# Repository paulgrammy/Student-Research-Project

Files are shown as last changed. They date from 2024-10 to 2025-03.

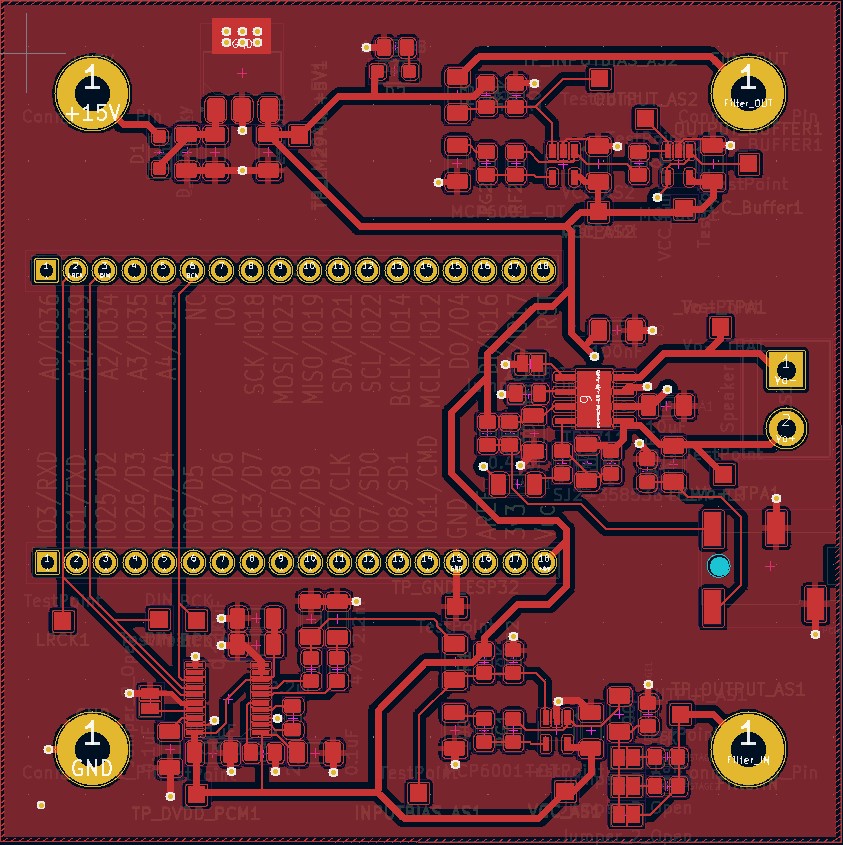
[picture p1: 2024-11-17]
doc/PCB Schematicc.jpg

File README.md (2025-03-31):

# Student-Research-Project-
Bluetooth signal receiver with filter stage and AUX/Speaker output.

UseCase description: 

This project seeks to help students more easily understand the effects of filters on electric signals by using sound. Since Music and/or audio is composed of frequencies across a spectrum (20Hz to 20kHz), one can hear what an Low/High Pass filter would do when fed audio signals. In my Student-Research project work, I try to design a PCB that shall overline this use case.

The PCB shall process analog converted audio signal coming from a Bluetooth-capable ESP32 board. The user shall connect the board at the input and output of any given filter and shall have the option to hear the filtered and unfiltered audio signals coming out with minimal noise and distortion.

Used platforms and ICs:

- ESP32 FireBeetle board:
    https://wiki.dfrobot.com/FireBeetle_Board_ESP32_E_SKU_DFR0654
- PCM5102 DAC:
    https://www.ti.com/product/PCM5102
- MCP6001 OPAMPS:
    https://ww1.microchip.com/downloads/en/DeviceDoc/MCP6001-1R-1U-2-4-1-MHz-Low-Power-Op-Amp-DS20001733L.pdf
- TPA711 Power AMP:
    https://www.ti.com/product/TPA711

Potential software solutions for the BluetoothRx interface:

https://github.com/pschatzmann/ESP32-A2DP

https://github.com/YetAnotherElectronicsChannel/ESP32_Bluetooth_Audio_Receiver

Books and Papers:

https://web.mit.edu/6.101/www/reference/op_amps_everyone.pdf

End result:
PCB 3D View

Conclusions: 
The board works with minimal distortion up to the OpAmps single supply limits, offering almost no phase lag.
Some layout optimizations can be carried out to lower the noise floor and make implementation in the labs easier.

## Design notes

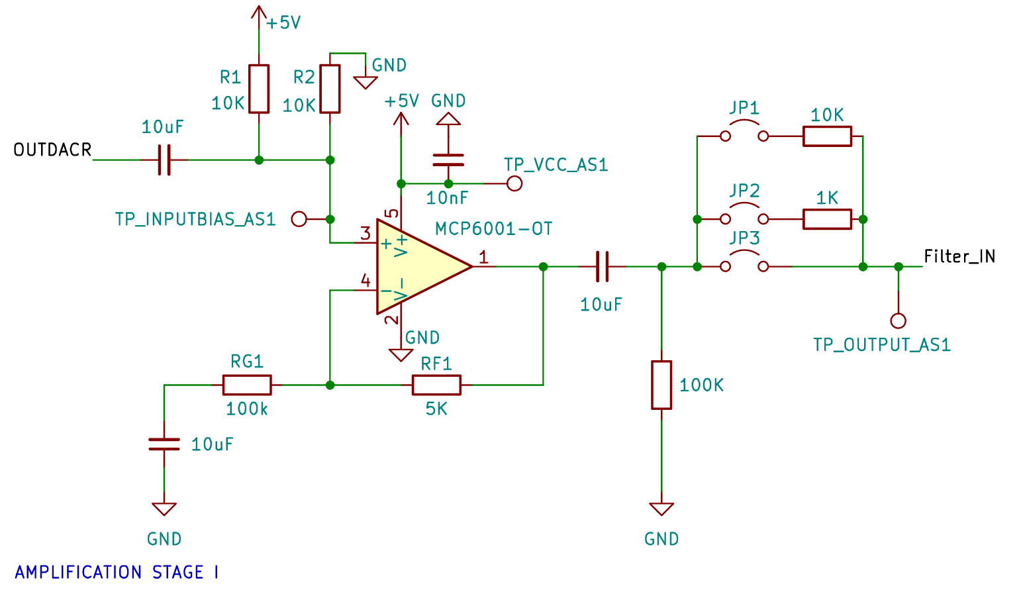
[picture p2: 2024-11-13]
doc/Schematic_OPAMP1.png

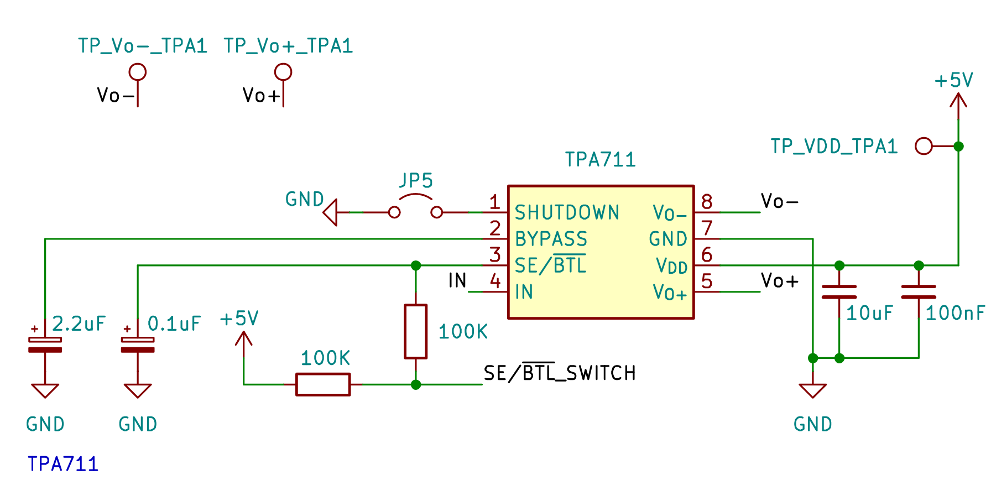
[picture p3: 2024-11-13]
doc/Schematic_POWERAMP.png

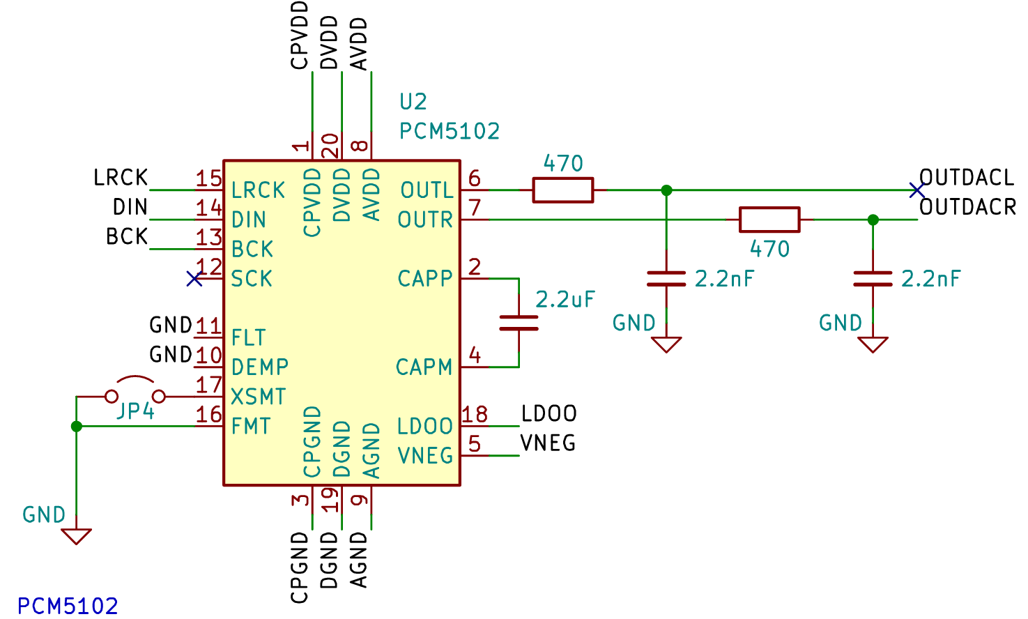
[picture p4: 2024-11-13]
doc/Schematic_DAC.png

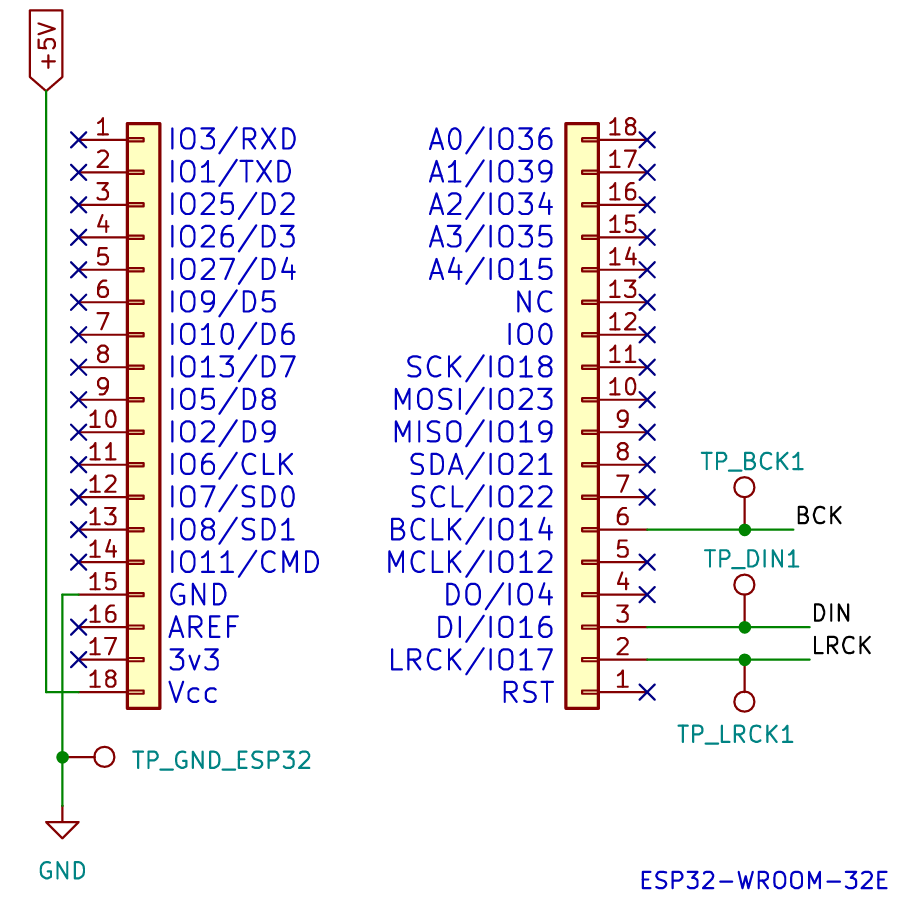
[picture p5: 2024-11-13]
doc/Schematic_ESP.png

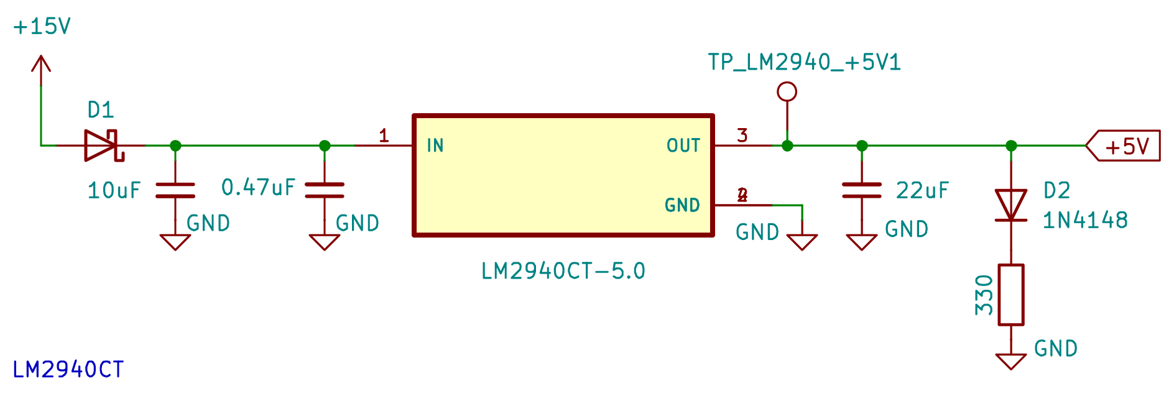
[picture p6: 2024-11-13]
doc/Schematic_LDO.png

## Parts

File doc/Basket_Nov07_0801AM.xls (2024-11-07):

SHOPPING BASKET
This is not an invoice
07-Nov-24 08:01:21
 | Mouser No | Mfr. No | Manufacturer | Customer No | Description | RoHS | Lifecycle | Order Qty. | Price (EUR) | Ext.: (EUR) | Comment
1 | 595-TPA711DR | TPA711DR | Texas Instruments |  | Audio Amplifiers 700mW Lw V Audio | RoHS Compliant |  | 3 | 1,09 € | 3,27 €
2 | 651-1729128 | 1729128 | Phoenix Contact |  | Fixed Terminal Blocks 2P 5.08mm 90DEG | RoHS Compliant By Exemption |  | 3 | 0,967 € | 2,90 €
3 | 595-PCM5102AQPWRQ1 | PCM5102AQPWRQ1 | Texas Instruments |  | Audio D/A Converter ICs 2VRMS DirectPath Audio Stereo DAC | RoHS Compliant |  | 3 | 5,04 € | 15,12 €
4 | 579-MCP6001UT-I/OT | MCP6001UT-I/OT | Microchip |  | Operational Amplifiers - Op Amps Single 1.8V 1MHz | RoHS Compliant |  | 6 | 0,279 € | 1,67 €
5 | 926-LM2940CT50LF01 | LM2940CT-5.0/LF01 | Texas Instruments |  | LDO Voltage Regulators 1-A, 26-V, high-PSRR, low-dropout voltage regulator 3-TO-220 | RoHS Compliant By Exemption |  | 3 | 1,74 € | 5,22 €
6 | 621-1N5819HW-F | 1N5819HW-7-F | Diodes Incorporated |  | Schottky Diodes & Rectifiers Vr/40V Io/1A T/R | RoHS Compliant |  | 3 | 0,233 € | 0,70 €
7 | 179-SJ3-35083A-TR | SJ3-35083A-TR | Same Sky |  | Phone Connectors Audio Jack, 3.5mm, Through Hole, 3 Conductors, 0 Switches | RoHS Compliant | New Product | 3 | 1,14 € | 3,42 €
8 | 78-1N4148W-HG3_A-08 | 1N4148W-HG3_A-08 | Vishay |  | Small Signal Switching Diodes |  | New Product | 3 | 0,307 € | 0,92 €
By submitting your order you agree to these terms and conditions. (https://www.mouser.de/saleterms) |  |  |  |  |  |  |  |  | Merchandise: | 33,22 €
Prices are reflected at the date and time shown. |  |  |  |  |  |  |  |  | Delivery Charge: | 20,00 €

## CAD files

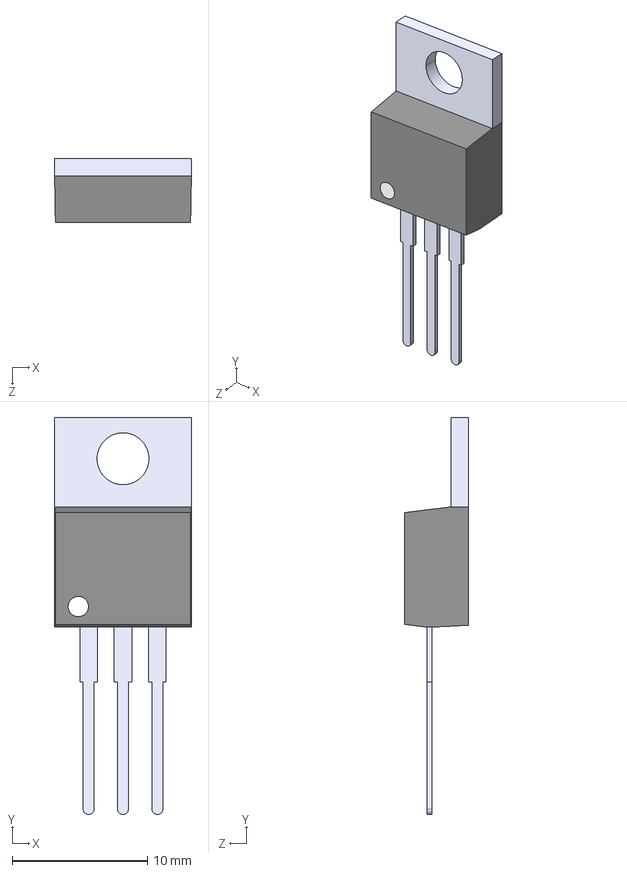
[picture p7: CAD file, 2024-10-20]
footprints/LM2940-5.0/LM2940CT-5.0.step
10.2 x 29.3 x 4.70 mm

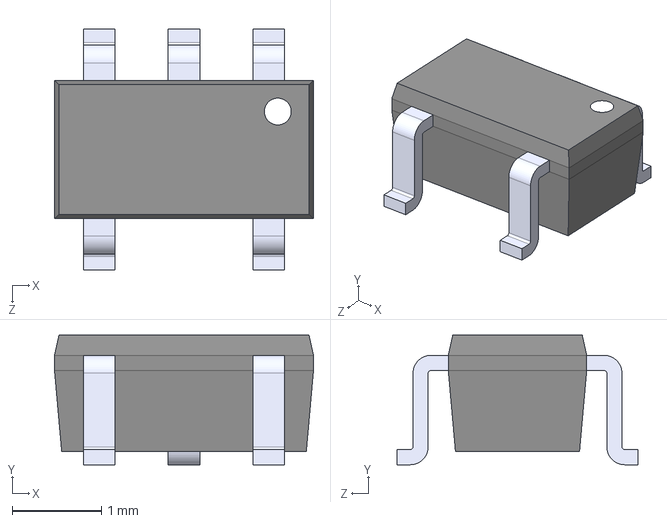
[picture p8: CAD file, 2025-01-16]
footprints/MCP6001UT-1_OT/MCP6001UT-I_OT.step
2.90 x 1.45 x 2.70 mm

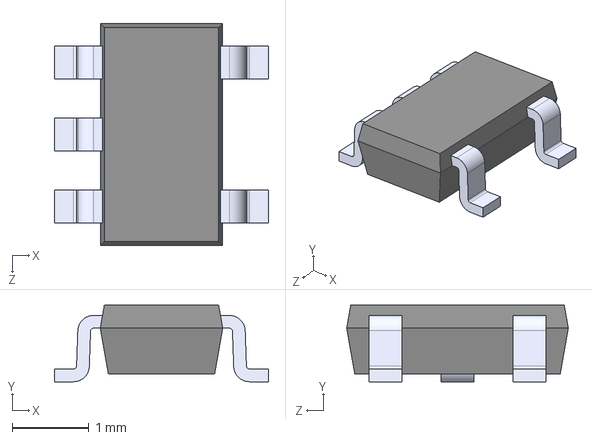
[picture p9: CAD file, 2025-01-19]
footprints/RT9080-33GJ5/RT9080-33GJ5.step
2.80 x 1.00 x 2.90 mm

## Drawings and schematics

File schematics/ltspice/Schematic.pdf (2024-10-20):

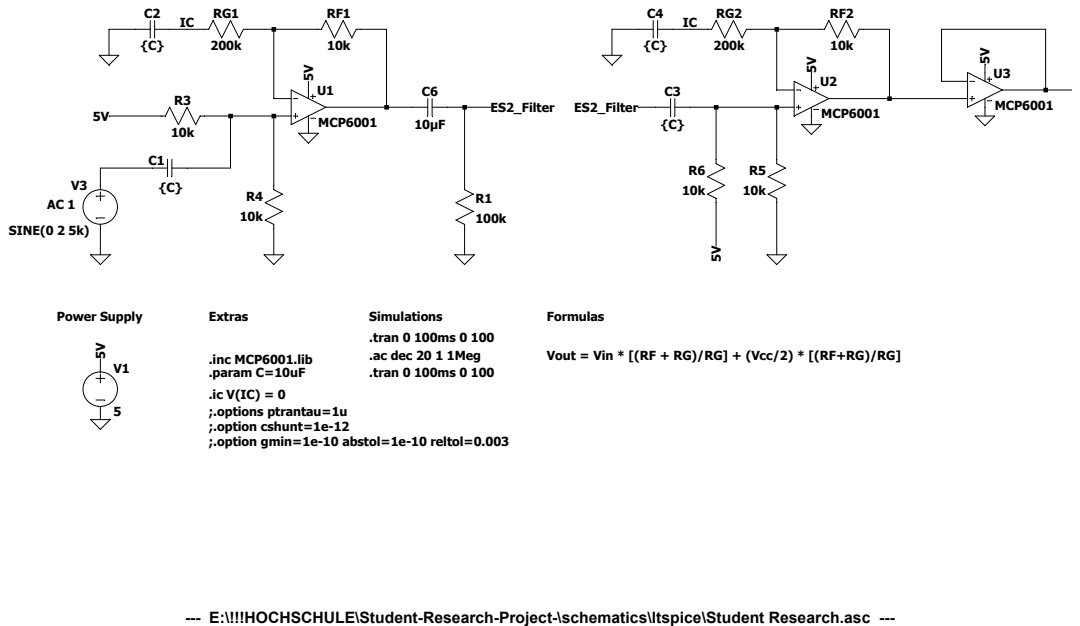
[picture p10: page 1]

.inc MCP6001.lib
.param C=10uF
;.options ptrantau=1u
;.option cshunt=1e-12
;.option gmin=1e-10 abstol=1e-10 reltol=0.003

Vout = Vin * [(RF + RG)/RG] + (Vcc/2) * [(RF+RG)/RG]

--- E:\!!!HOCHSCHULE\Student-Research-Project-\schematics\ltspice\Student Research.asc ---

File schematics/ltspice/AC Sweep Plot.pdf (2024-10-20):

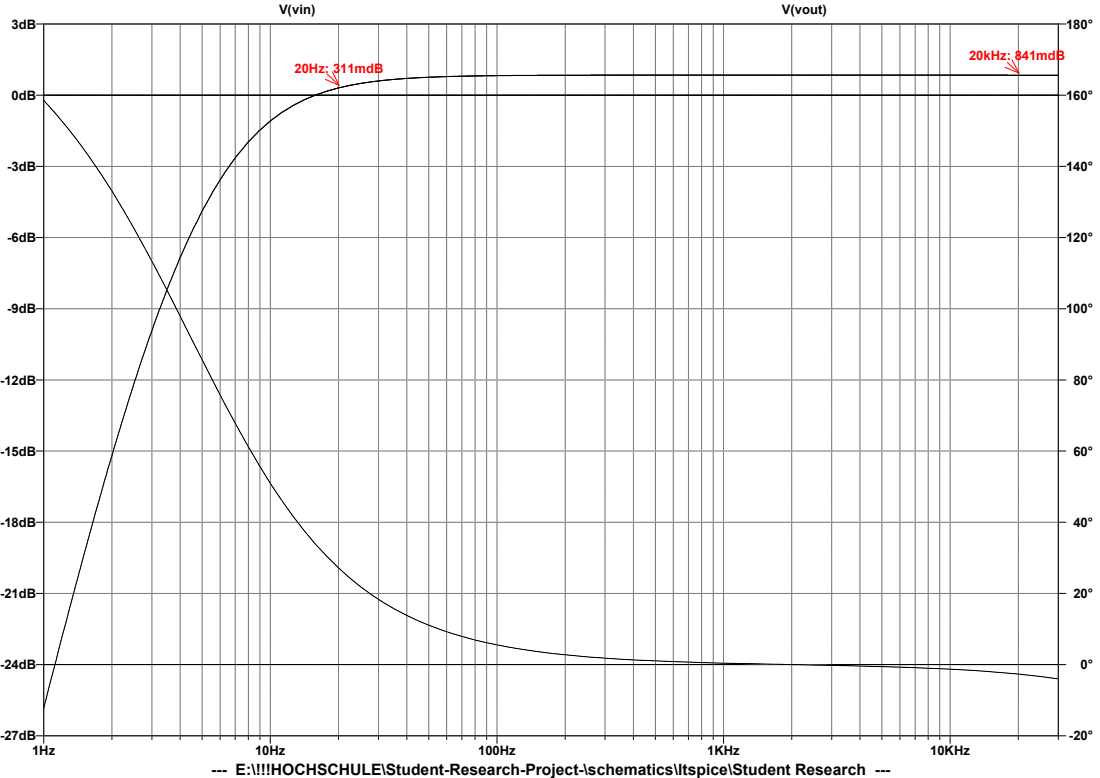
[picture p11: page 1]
1KHz; 10KHz; V(vin); V(vout); 20Hz: 311mdB; 20kHz: 841mdB

--- E:\!!!HOCHSCHULE\Student-Research-Project-\schematics\ltspice\Student Research ---

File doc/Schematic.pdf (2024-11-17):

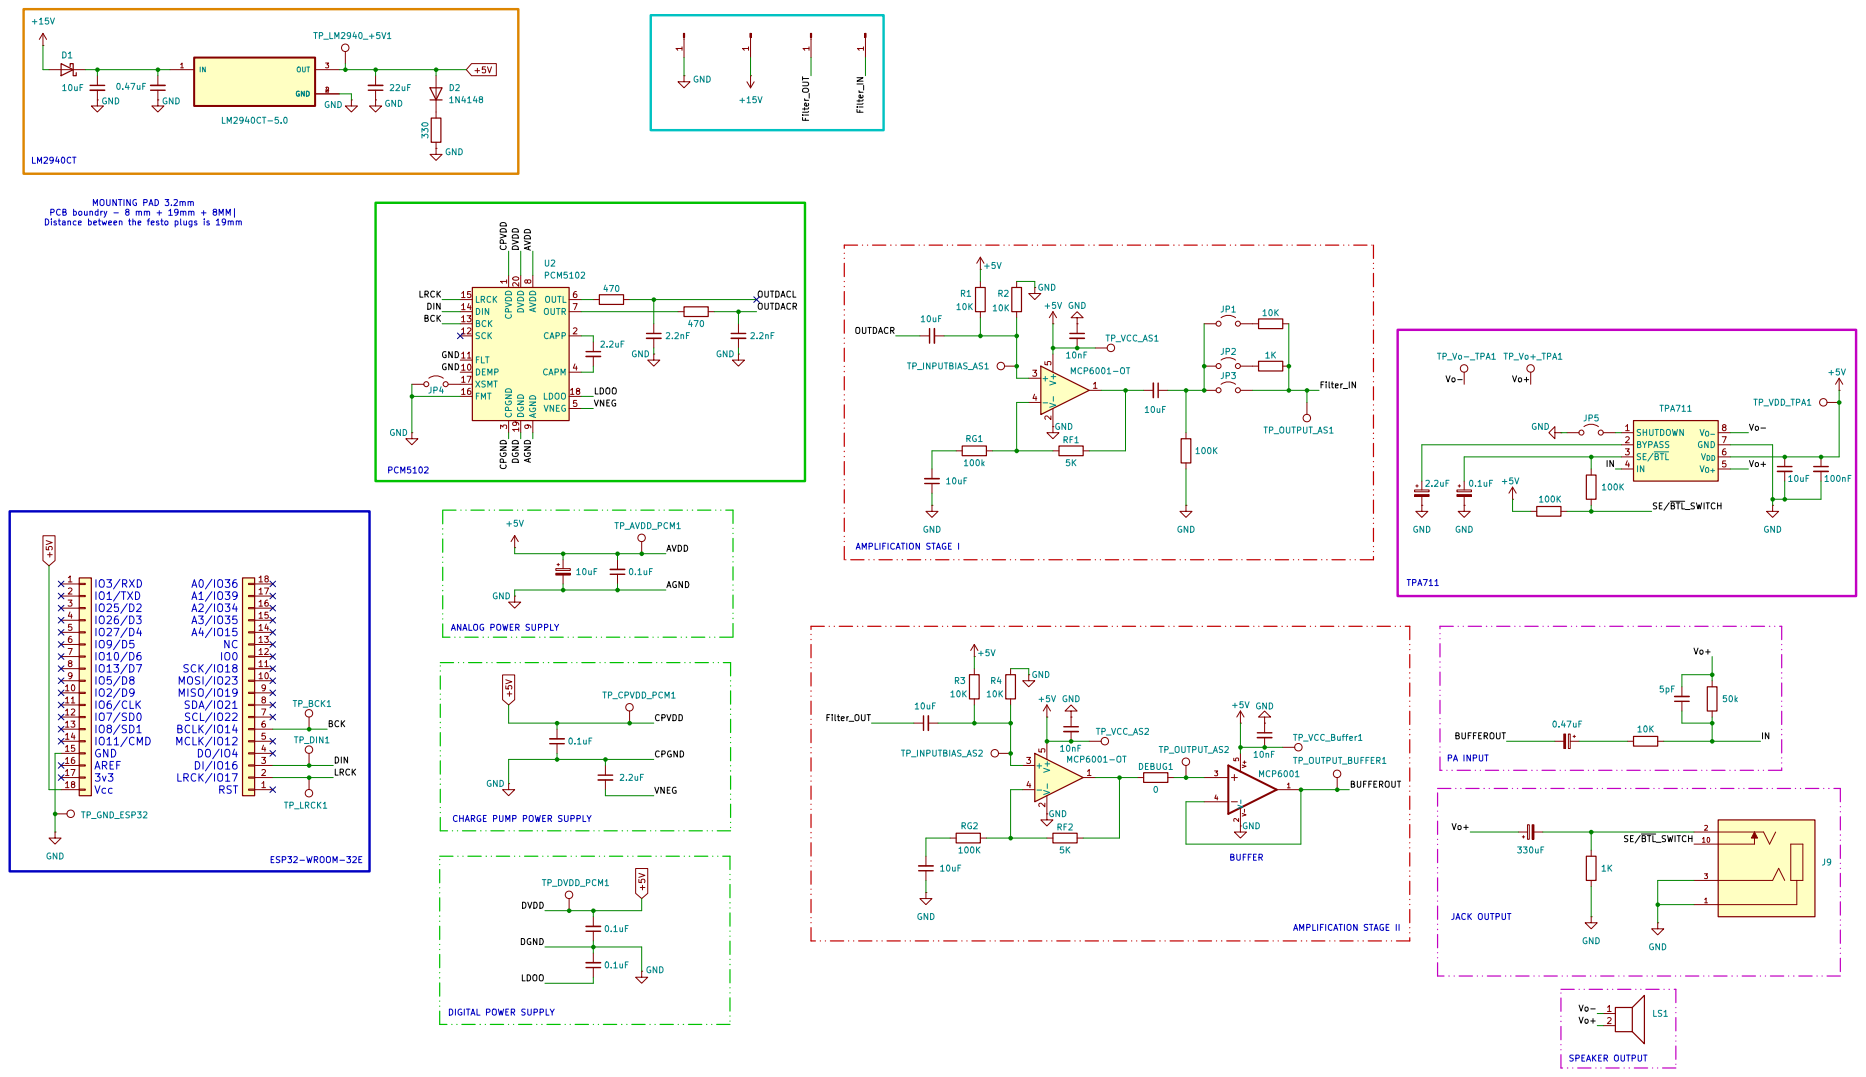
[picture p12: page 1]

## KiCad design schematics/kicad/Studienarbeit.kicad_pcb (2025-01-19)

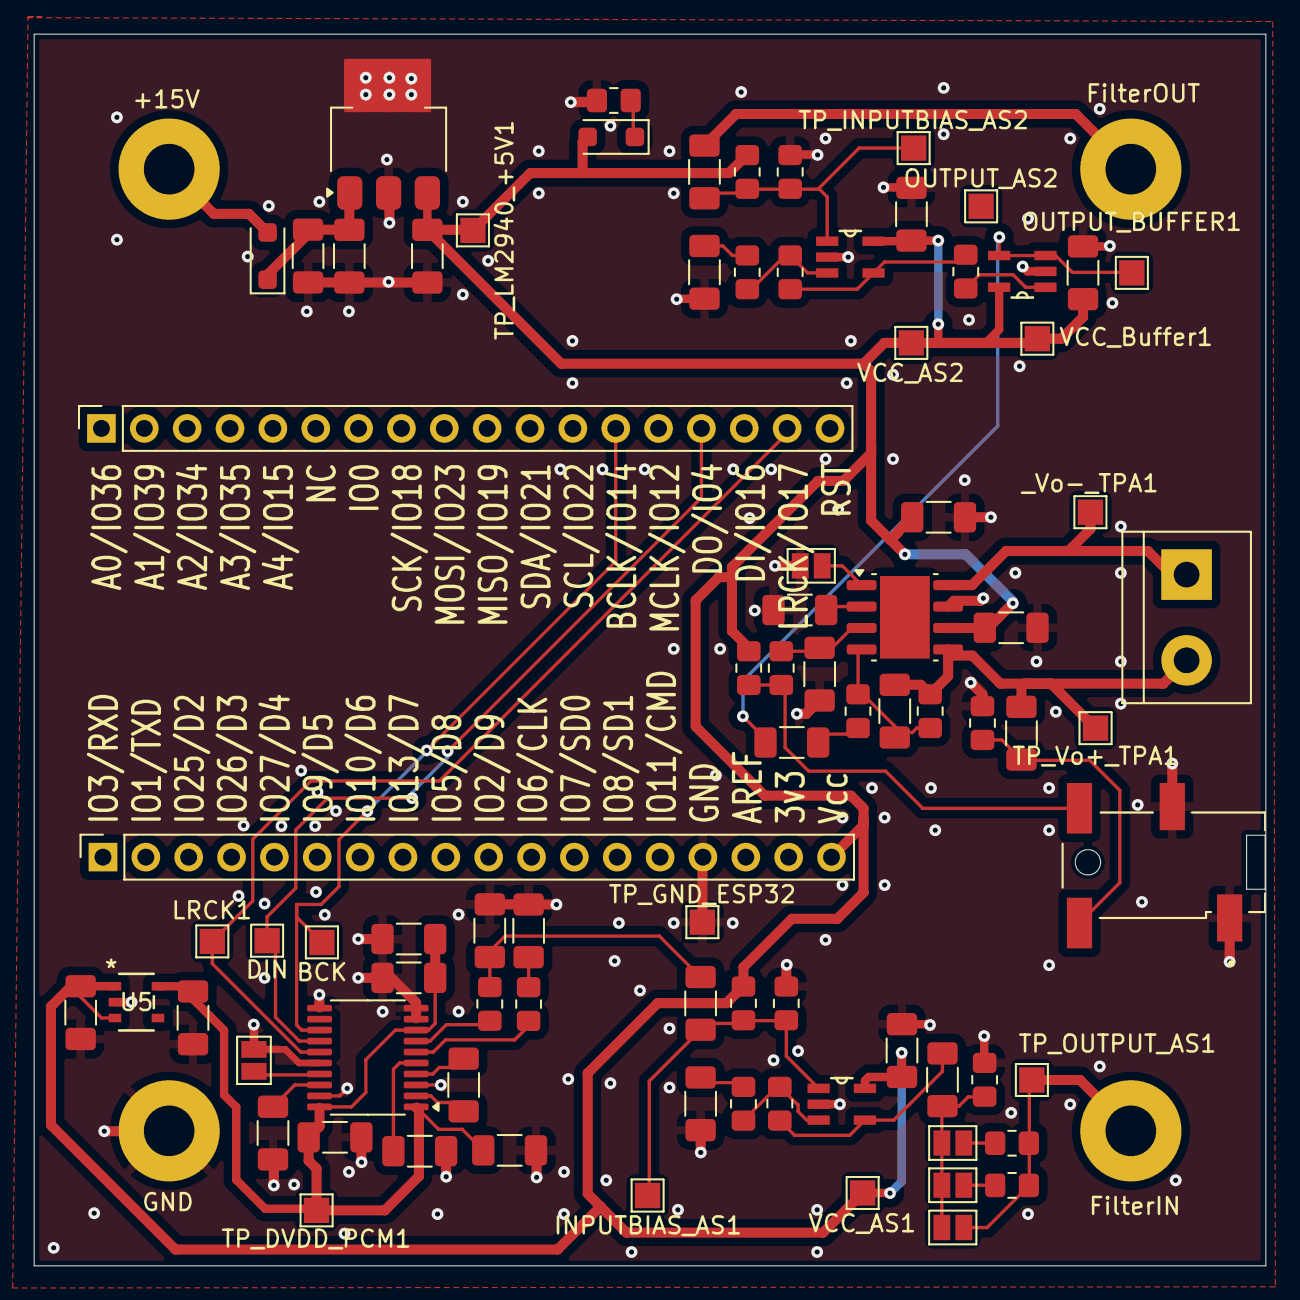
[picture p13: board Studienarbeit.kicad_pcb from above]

Board: 2 copper layers, 73.0 x 73.0 mm, 87 parts (0 on the bottom side), 42 nets.

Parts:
BCK: TestPoint; TestPoint_Pad_1.5x1.5mm
C1_APS_PCM5102: 10uF; C_1206_3216Metric_Pad1.33x1.80mm_HandSolder
C1_CPPS_PCM1, C1_DPS_PCM1, C2_APS_PCM5102, C2_DPS_PCM1: 0.1uF; C_1206_3216Metric_Pad1.33x1.80mm_HandSolder
C2_CPPS_PCM1: 2.2uF; C_1206_3216Metric_Pad1.33x1.80mm_HandSolder
CA_PCM5102: 2.2uF; C_1206_3216Metric_Pad1.33x1.80mm_HandSolder
CB_TPA1: 2.2uF; C_1206_3216Metric_Pad1.33x1.80mm_HandSolder
CF_TPA711: 5pF; C_1206_3216Metric_Pad1.33x1.80mm_HandSolder
CG1_PCM5102, CG2_PCM5102: 2.2nF; C_1206_3216Metric_Pad1.33x1.80mm_HandSolder
CI_TPA711: 0.47uF; C_1206_3216Metric_Pad1.33x1.80mm_HandSolder
C_COUPLING_AMPSTAGE1: 10uF; C_1206_3216Metric_Pad1.33x1.80mm_HandSolder
C_COUPLING_AMPSTAGE2, C_COUPLING_AMPSTAGE3, C_COUPLING_AMPSTAGE4: 10nF; C_1206_3216Metric_Pad1.33x1.80mm_HandSolder
C_GND_AMPSTAGE1, C_GND_AMPSTAGE2, C_GND_AMPSTAGE3: 10uF; C_1206_3216Metric_Pad1.33x1.80mm_HandSolder
C_INPUT_LDO1: 0.47uF; C_1206_3216Metric_Pad1.33x1.80mm_HandSolder
C_INPUT_RT1: 22uF; C_1206_3216Metric_Pad1.33x1.80mm_HandSolder
C_INPUT_RT9080: 1uF; C_1206_3216Metric_Pad1.33x1.80mm_HandSolder
C_INPUT_TPA1, C_INPUT_TPA3: 10uF; C_1206_3216Metric_Pad1.33x1.80mm_HandSolder
C_INPUT_TPA2: 100nF; C_1206_3216Metric_Pad1.33x1.80mm_HandSolder
C_IN_+15V_1: 10uF; C_1206_3216Metric_Pad1.33x1.80mm_HandSolder
C_IN_AMPSTAGE1: 10uF; C_1206_3216Metric_Pad1.33x1.80mm_HandSolder
C_OUTPUT_LDO1: 22uF; C_1206_3216Metric_Pad1.33x1.80mm_HandSolder
C_SE/BTL_TPA1: 0.1uF; C_1206_3216Metric_Pad1.33x1.80mm_HandSolder
D1: D_Schottky; D_SOD-123F
D2: 1N4148; D_SOD-123F
DEBUG1: 0; R_0805_2012Metric_Pad1.20x1.40mm_HandSolder
DIN: TestPoint; TestPoint_Pad_1.5x1.5mm
INPUTBIAS_AS1: TestPoint; TestPoint_Pad_1.5x1.5mm
J2, J3: Conn_01x18; PinSocket_1x18_P2.54mm_Vertical
J4, J5, J6, J7: Conn_01x01_Pin; FestoBoard_Drill_Hole
J9: SJ2-35853B-SMT-TR; CUI_SJ2-35853B-SMT-TR
JP1, JP2, JP3, JP4, JP5: Jumper_2_Open; SolderJumper-2_P1.3mm_Open_Pad1.0x1.5mm
LRCK1: TestPoint; TestPoint_Pad_1.5x1.5mm
LS1: Speaker; TerminalBlock_bornier-2_P5.08mm
OUTPUT_AS2: TestPoint; TestPoint_Pad_1.5x1.5mm
OUTPUT_BUFFER1: TestPoint; TestPoint_Pad_1.5x1.5mm
R1, R2, R3, R4: 10K; R_0805_2012Metric_Pad1.20x1.40mm_HandSolder
R11: 1K; R_0805_2012Metric_Pad1.20x1.40mm_HandSolder
R12, R13: 100K; R_0805_2012Metric_Pad1.20x1.40mm_HandSolder
RF1, RF2: 5K; R_0805_2012Metric_Pad1.20x1.40mm_HandSolder
RF_TPA711: 50k; R_0805_2012Metric_Pad1.20x1.40mm_HandSolder
RG1: 100k; R_0805_2012Metric_Pad1.20x1.40mm_HandSolder
RG2: 100K; R_0805_2012Metric_Pad1.20x1.40mm_HandSolder
RI_TPA711: 10K; R_0805_2012Metric_Pad1.20x1.40mm_HandSolder
ROUTDACL1: 470; R_0805_2012Metric_Pad1.20x1.40mm_HandSolder
ROUTDACR1: 470; R_0805_2012Metric_Pad1.20x1.40mm_HandSolder
R_COUPLING_AMPSTAGE1: 100K; R_0805_2012Metric_Pad1.20x1.40mm_HandSolder
R_COUPLING_AMPSTAGE2: 10K; R_0805_2012Metric_Pad1.20x1.40mm_HandSolder
R_COUPLING_AMPSTAGE3: 1K; R_0805_2012Metric_Pad1.20x1.40mm_HandSolder
STATUS_LED1: 330; R_0805_2012Metric_Pad1.20x1.40mm_HandSolder
TP_DVDD_PCM1: TestPoint; TestPoint_Pad_1.5x1.5mm
TP_GND_ESP32: TestPoint; TestPoint_Pad_1.5x1.5mm
TP_INPUTBIAS_AS2: TestPoint; TestPoint_Pad_1.5x1.5mm
TP_LM2940_+5V1: TestPoint; TestPoint_Pad_1.5x1.5mm
TP_OUTPUT_AS1: TestPoint; TestPoint_Pad_1.5x1.5mm
TP_Vo+_TPA1: TestPoint; TestPoint_Pad_1.5x1.5mm
U1, U3, U4: MCP6001-OT; SOT95P270X145-5N
U2: PCM5102; TSSOP-20_4.4x6.5mm_P0.65mm
U5: RT9080-33GJ5; TSOT-23-5_RIT-L
U6: TPA711; Texas_R-PDSO-G8_EP2.95x4.9mm_Mask2.4x3.1mm
U7: LM2940CT-5.0; SOT-223
VCC_AS1, VCC_AS2: TestPoint; TestPoint_Pad_1.5x1.5mm
VCC_Buffer1: TestPoint; TestPoint_Pad_1.5x1.5mm
_Vo-_TPA1: TestPoint; TestPoint_Pad_1.5x1.5mm

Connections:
+3v3: C1_APS_PCM5102.1, C1_CPPS_PCM1.2, C1_DPS_PCM1.2, C2_APS_PCM5102.2, C_INPUT_RT1.2, TP_DVDD_PCM1.1, U2.1 (CPVDD), U2.8 (AVDD), U2.20 (DVDD), U5.5 (VOUT)
+5V: C_COUPLING_AMPSTAGE2.2, C_COUPLING_AMPSTAGE3.2, C_COUPLING_AMPSTAGE4.2, C_INPUT_RT9080.2, C_INPUT_TPA1.1, C_INPUT_TPA2.1, C_OUTPUT_LDO1.2, D2.2 (A), J2.18, R1.2, R3.2, R12.2, TP_LM2940_+5V1.1, U1.5 (V+), U3.5 (V+), U4.5 (V+), U5.1 (VIN), U5.3 (EN), U6.6 (V_{DD}), U7.3 (OUT), VCC_AS1.1, VCC_AS2.1, VCC_Buffer1.1
+15V: D1.2 (A), J5.1
/BCK: BCK.1, J3.13, U2.13 (BCK)
/BUFFEROUT: CI_TPA711.2, OUTPUT_BUFFER1.1, U3.3 (-), U3.4
/DIN: DIN.1, J3.15, U2.14 (DIN)
/Filter_IN: J7.1, JP3.2 (B), R_COUPLING_AMPSTAGE2.1, R_COUPLING_AMPSTAGE3.1, TP_OUTPUT_AS1.1
/Filter_OUT: C_IN_AMPSTAGE1.1, J6.1
/IN: CF_TPA711.1, RF_TPA711.2, RI_TPA711.2, U6.4 (IN)
/LDOO: C2_DPS_PCM1.1, U2.18 (LDOO)
/LRCK: J3.17, LRCK1.1, U2.15 (LRCK)
/OUTDACL: CG1_PCM5102.1, ROUTDACL1.2
/OUTDACR: CG2_PCM5102.1, C_GND_AMPSTAGE3.1, ROUTDACR1.2
/SE/~BTL_SWITCH: J9.10, R12.1, R13.1
/VNEG: C2_CPPS_PCM1.2, U2.5 (VNEG)
/Vo+: CF_TPA711.2, C_INPUT_TPA3.1, LS1.2, RF_TPA711.1, TP_Vo+_TPA1.1, U6.5 (V_{O+})
/Vo-: LS1.1, U6.8 (V_{O-}), _Vo-_TPA1.1
GND: C1_APS_PCM5102.2, C1_CPPS_PCM1.1, C1_DPS_PCM1.1, C2_APS_PCM5102.1, C2_CPPS_PCM1.1, C2_DPS_PCM1.2, CB_TPA1.2, CG1_PCM5102.2, CG2_PCM5102.2, C_COUPLING_AMPSTAGE2.1, C_COUPLING_AMPSTAGE3.1, C_COUPLING_AMPSTAGE4.1, C_GND_AMPSTAGE1.1, C_GND_AMPSTAGE2.1, C_INPUT_LDO1.1, C_INPUT_RT1.1, C_INPUT_RT9080.1, C_INPUT_TPA1.2, C_INPUT_TPA2.2, C_IN_+15V_1.2, C_OUTPUT_LDO1.1, C_SE/BTL_TPA1.2, J2.15, J4.1, J9.1, J9.3, JP4.1 (A), JP5.1 (A), R2.2, R4.2, R11.2, R_COUPLING_AMPSTAGE1.1, STATUS_LED1.1, TP_GND_ESP32.1, U1.2 (V-), U2.3 (CPGND), U2.9 (AGND), U2.10 (DEMP), U2.11 (FLT), U2.16 (FMT), U2.19 (DGND), U3.2 (V-), U4.2 (V-), U5.2 (GND), U6.7 (GND), U7.2 (GND), U7.4 (GND)
unnamed: CI_TPA711.1, RI_TPA711.1
unnamed: C_COUPLING_AMPSTAGE1.2, RF1.2, U4.4
unnamed: C_GND_AMPSTAGE1.2, RG1.1
unnamed: C_GND_AMPSTAGE2.2, RG2.1
unnamed: C_INPUT_TPA3.2, J9.2, R11.1
unnamed: C_INPUT_LDO1.2, C_IN_+15V_1.1, D1.1 (K), U7.1 (IN)
unnamed: D2.1 (K), STATUS_LED1.2
unnamed: DEBUG1.1, RF2.2, U1.4
unnamed: C_COUPLING_AMPSTAGE1.1, JP1.1 (A), JP2.1 (A), JP3.1 (A), R_COUPLING_AMPSTAGE1.2
unnamed: JP1.2 (B), R_COUPLING_AMPSTAGE2.2
unnamed: JP2.2 (B), R_COUPLING_AMPSTAGE3.2
unnamed: JP4.2 (B), U2.17 (XSMT)
unnamed: JP5.2 (B), U6.1 (SHUTDOWN)
unnamed: C_IN_AMPSTAGE1.2, R3.1, R4.1, TP_INPUTBIAS_AS2.1, U1.1 (+)
unnamed: RF2.1, RG2.2, U1.3 (-)
unnamed: CA_PCM5102.2, U2.4 (CAPM)
unnamed: CA_PCM5102.1, U2.2 (CAPP)
unnamed: ROUTDACL1.1, U2.6 (OUTL)
unnamed: ROUTDACR1.1, U2.7 (OUTR)
unnamed: DEBUG1.2, U3.1 (+)
unnamed: C_GND_AMPSTAGE3.2, INPUTBIAS_AS1.1, R1.1, R2.1, U4.1 (+)
unnamed: RF1.1, RG1.2, U4.3 (-)
unnamed: CB_TPA1.1, U6.2 (BYPASS)
unnamed: C_SE/BTL_TPA1.1, R13.2, U6.3 (SE/~BTL)

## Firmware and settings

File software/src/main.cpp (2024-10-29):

#include <stdio.h>
#include <Arduino.h>
#include "AudioTools.h"
#include "BluetoothA2DPSink.h"

I2SStream i2s;
BluetoothA2DPSink a2dp_sink(i2s);

#define LED_GPIO GPIO_NUM_2

void setup() {
  auto config = i2s.defaultConfig();

  config.pin_bck = 14;
  config.pin_ws = 17;
  config.pin_data = 16;

  i2s.begin(config);

  a2dp_sink.start("MyMusic");
}

void loop() {
}

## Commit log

2024-10-09 Imported LTSpice base schematic.
2024-10-09 Imported KiCAD schematics.
    [Studienarbeit.kicad_pcb, Studienarbeit.kicad_sch]
2024-10-09 Added notes for potential DAC PCB design.
2024-10-18 Updated LTSpice schematics.
2024-10-18 LTSpice: Added AC-Coupling caps at output of first amp stage.
2024-10-18 KiCad: rewired PCM5120 I/O pins and dimentioned Rs and Cs
    [Studienarbeit.kicad_sch]
2024-10-18 KiCad: Rewired the TPA711 I/Os and dimentioned Rs and Cs
    [Studienarbeit.kicad_sch]
2024-10-18 KiCad: Grafics.
    [Studienarbeit.kicad_sch]
2024-10-18 KiCad: Added links to IC schematics.
    [Studienarbeit.kicad_sch]
2024-10-18 KiCad: Fixed a few ERC errors.
    [Studienarbeit.kicad_sch]
2024-10-18 KiCad: Dimentioned Cs.
    [Studienarbeit.kicad_sch]
2024-10-18 Added footprint folder for imported footprints.
    [Studienarbeit.kicad_sch]
2024-10-18 Added ESP32 Footprint.
    [Studienarbeit.kicad_sch]
2024-10-18 KiCad: Draft of PCB.
    [Studienarbeit.kicad_pcb, Studienarbeit.kicad_sch]
2024-10-20 KiCad: Added an LDO for stable supply voltage.
    [LM2940CT-5.0.step, Studienarbeit.kicad_pcb]
2024-10-20 LTSpice: Printed plots for report.
2024-10-20 Updated printed images.
2024-10-20 KiCad: Added test points in the schematic.
    [Studienarbeit.kicad_sch]
2024-10-22 Replace ESP32 Schematic with header pins.
    [Studienarbeit.kicad_sch]
2024-10-22 Updated schematic.
    [Studienarbeit.kicad_sch]
2024-10-24 Updated PCB.
    [Studienarbeit.kicad_pcb, Studienarbeit.kicad_sch]
2024-10-29 Updated the pcb schematic.
    [Studienarbeit.kicad_pcb]
2024-10-29 LTSpice: added jumper resistors for gain control.
2024-10-29 KiCad: Added jumper wires and resistors for gain control.
    [Studienarbeit.kicad_pcb]
2024-10-29 KiCad: rerouted the jumpers.
    [Studienarbeit.kicad_sch]
2024-11-04 Updated PCB based on feedback (1).
    [Studienarbeit.kicad_pcb, Studienarbeit.kicad_sch]
2024-11-07 Updated the PCB with prof feedback.
    [Studienarbeit.kicad_pcb, Studienarbeit.kicad_sch]
2024-11-07 Updated the parts list.
    [Basket_Nov07_0801AM.xls, Studienarbeit.kicad_pcb, Studienarbeit.kicad_sch]
2024-11-07 Added screenshots of simulation.
    [Studienarbeit.kicad_sch]
2024-11-13 Added schematic screenshots.
2024-11-13 Updated the audio jack to a switching jack.
    [Studienarbeit.kicad_pcb, Studienarbeit.kicad_sch]
2024-11-13 Rezolved Jack footprint issue.
    [Studienarbeit.kicad_pcb]
2024-11-13 Updated design.
    [Studienarbeit.kicad_pcb]
2024-11-17 Updated interface with changes from Prof.
    [Studienarbeit.kicad_sch]
2024-11-20 Last board updates before ordering.
    [Studienarbeit.kicad_pcb, Studienarbeit.kicad_sch]
2025-01-16 Updated MCP footprint and symbol
    [MCP6001UT-I_OT.step, Studienarbeit.kicad_pcb, Studienarbeit.kicad_sch]
2025-01-16 Re-Added copper Layer
    [Studienarbeit.kicad_pcb]
2025-01-16 Updated output pins of the ESP
    [Studienarbeit.kicad_pcb, Studienarbeit.kicad_sch]
2025-01-19 Replaced footprint with the one from the prof.
    [RT9080-33GJ5.step, Studienarbeit.kicad_pcb]
